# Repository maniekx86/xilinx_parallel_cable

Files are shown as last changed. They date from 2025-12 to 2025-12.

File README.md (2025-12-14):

# xilinx_parallel_cable
Another clone of Xilinx parallel cable. The logic is based on what I had in my spare parts at the time of design (7404 + 7405).

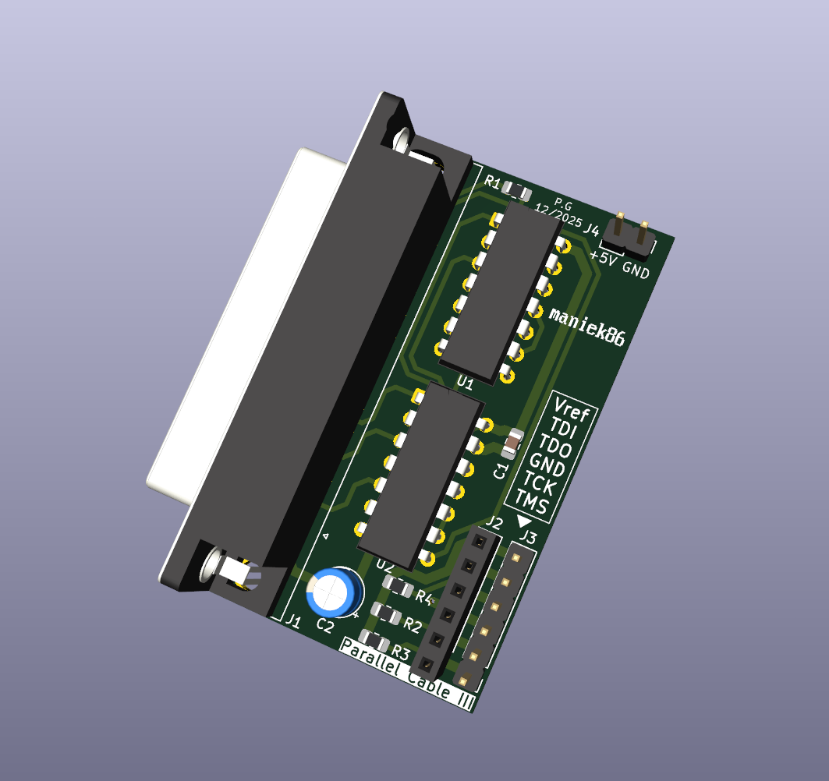
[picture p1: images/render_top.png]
Render top


## Usage
Connect this device to the PC using a DB-25 cable and provide +5V power to the J4 header, and you're ready to go.

## Pinout
### J4 (74xx logic power)
| Pin | Function  |
|-----|---|
| 1 | GND |
| 2 | +5V |

### J2 & J3 (connected together)
| Pin | Function  | Note |
|-----|---|---|
| 1 | TMS | |
| 2 | TCK | |
| 3 | GND | |
| 4 | TDO | |
| 5 | TDI | |
| 6 | Vref | Connect to target device power |

## BOM
| Marking | Value/Element | Package | Amount |
|---|---|---|---|
| C1 | 100n | SMD 0805 | 1 |
| C2 | 10u | Radial D5.0mm P2.50mm | 1 |
| J1 | DB-25 female connector | | 1 |
| J2 | Pin socket 1x6 | P2.54mm | 1 |
| J3 | Pin header 1x6 | P2.54mm | 1 |
| J4 | Pin header 1x2 | P2.54mm | 1 |
| R1 | 100 | SMD 0805 | 1 |
| R2-R4 | 470 (330 can be used too) | SMD 0805 | 3 |
| U1 | 7405 | DIP-14 | 1 | 
| U2 | 7404 | DIP-14 | 1 |

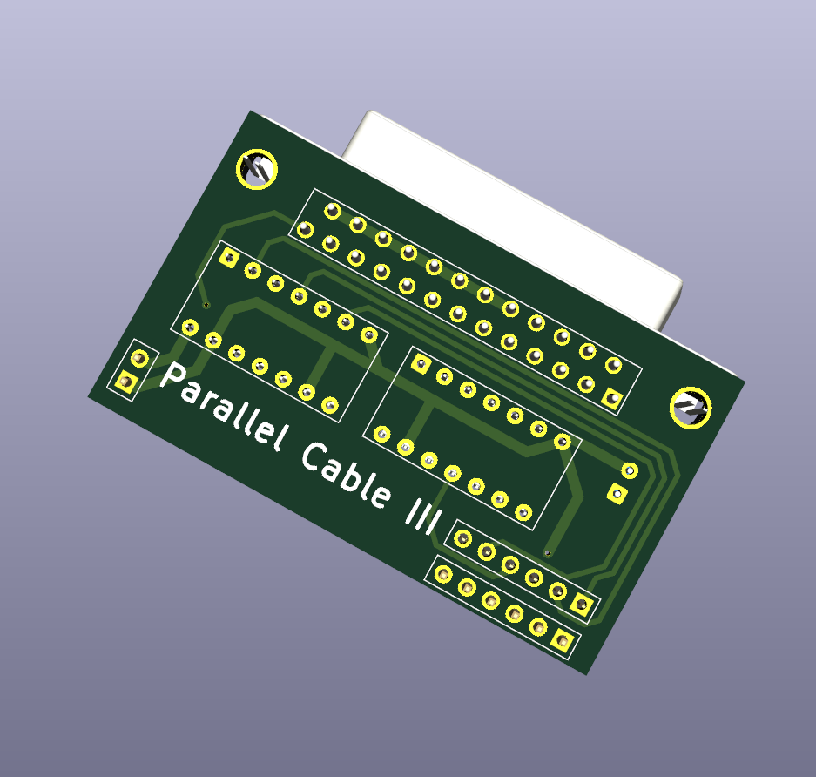
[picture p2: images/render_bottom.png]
Render bottom


## Prototype
This design was tested on prototype PCB
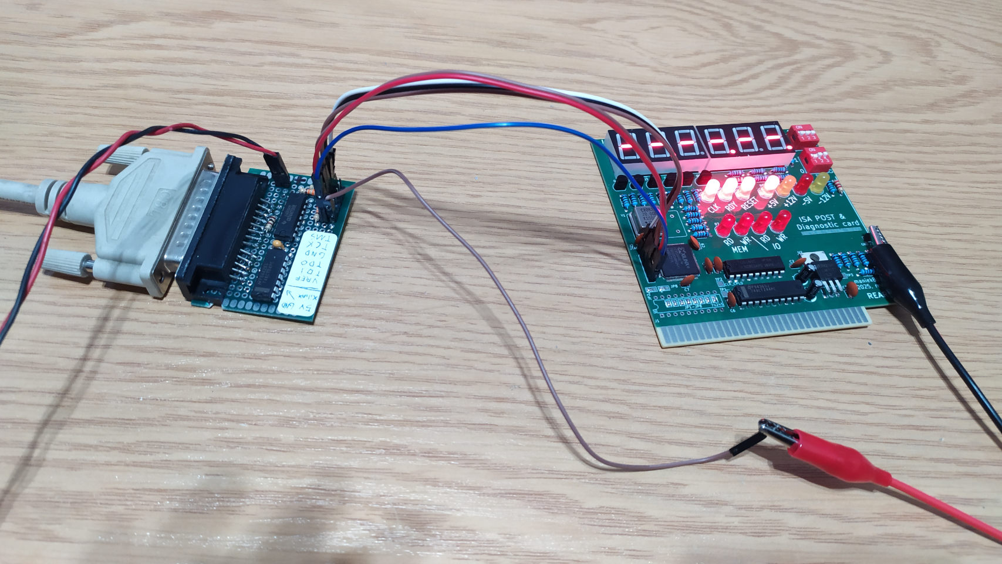
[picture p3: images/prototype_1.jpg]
Prototype 1st image

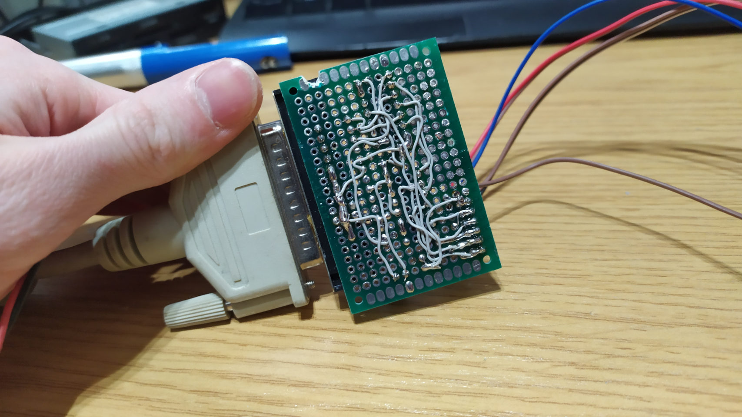
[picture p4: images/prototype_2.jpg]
Prototype 2nd image


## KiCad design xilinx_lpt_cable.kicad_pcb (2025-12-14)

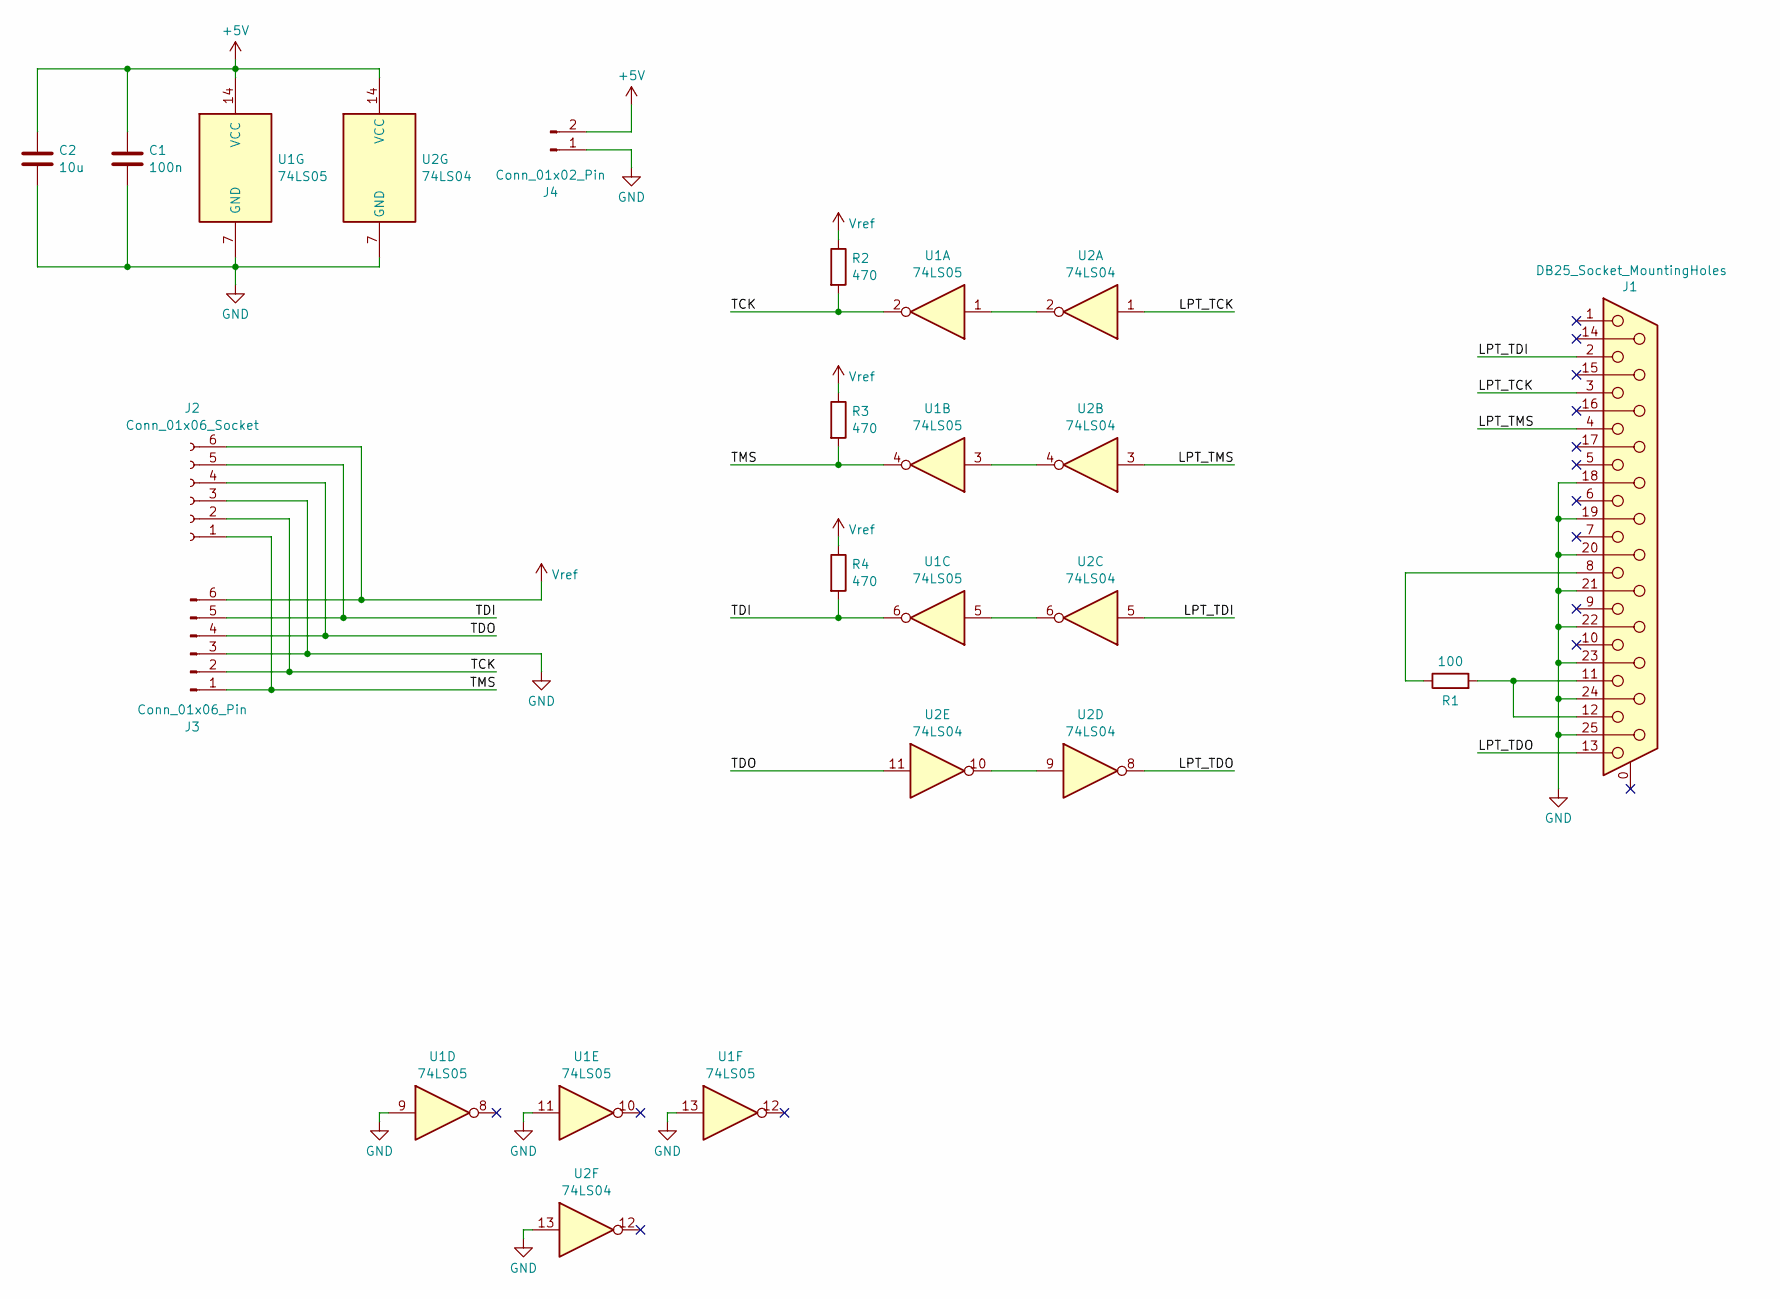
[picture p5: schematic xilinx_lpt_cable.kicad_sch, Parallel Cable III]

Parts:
C1: 100n; C_0805_2012Metric_Pad1.18x1.45mm_HandSolder
C2: 10u; CP_Radial_D5.0mm_P2.50mm
J1: DB25_Socket_MountingHoles; DSUB-25_Socket_Horizontal_P2.77x2.84mm_EdgePinOffset4.94mm_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
J2: Conn_01x06_Socket; PinSocket_1x06_P2.54mm_Vertical
J3: Conn_01x06_Pin; PinHeader_1x06_P2.54mm_Vertical
J4: Conn_01x02_Pin; PinHeader_1x02_P2.54mm_Vertical
R1: 100; R_0805_2012Metric_Pad1.20x1.40mm_HandSolder
R2, R3, R4: 470; R_0805_2012Metric_Pad1.20x1.40mm_HandSolder
U1: 74LS05; DIP-14_W7.62mm
U2: 74LS04; DIP-14_W7.62mm

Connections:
+5V: C1.1, C2.1, J4.2, U1.14 (VCC), U2.14 (VCC)
/LPT_TCK: J1.3, U2.1
/LPT_TDI: J1.2, U2.5
/LPT_TDO: J1.13, U2.8
/LPT_TMS: J1.4, U2.3
/TCK: J2.2, J3.2, R2.2, U1.2
/TDI: J2.5, J3.5, R4.2, U1.6
/TDO: J2.4, J3.4, U2.11
/TMS: J2.1, J3.1, R3.2, U1.4
GND: C1.2, C2.2, J1.18, J1.19, J1.20, J1.21, J1.22, J1.23, J1.24, J1.25, J2.3, J3.3, J4.1, U1.7 (GND), U1.9, U1.11, U1.13, U2.7 (GND), U2.13
unnamed: J1.8, R1.1
unnamed: J1.11, J1.12, R1.2
unnamed: U1.1, U2.2
unnamed: U1.3, U2.4
unnamed: U1.5, U2.6
unnamed: U2.9, U2.10
Vref: J2.6, J3.6, R2.1, R3.1, R4.1

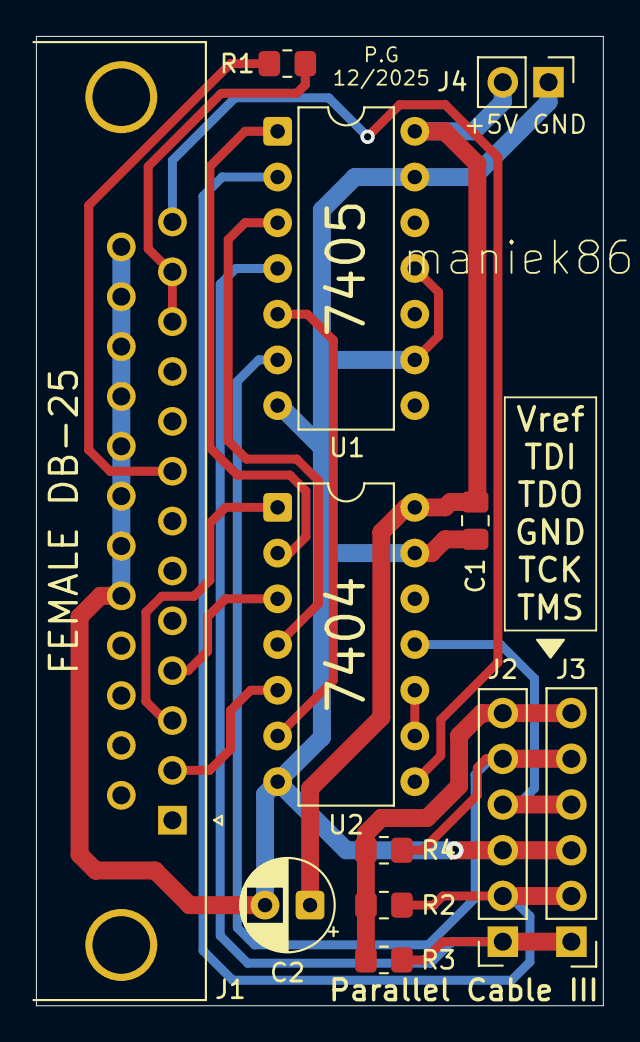
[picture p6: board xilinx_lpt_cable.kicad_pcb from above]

Board: 2 copper layers, 31.5 x 53.8 mm, 12 parts (0 on the bottom side), 17 nets.

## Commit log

2025-12-14 Enhance README with usage, pinout, and BOM details
    Expanded the README with detailed usage instructions, pinout information, BOM, and prototype images.
2025-12-14 Compress prototype images
